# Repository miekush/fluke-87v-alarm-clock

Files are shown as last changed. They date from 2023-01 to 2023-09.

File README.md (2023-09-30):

# Fluke 87V Alarm Clock
ATMEGA328P based Alarm Clock PCB for the Fluke 87V

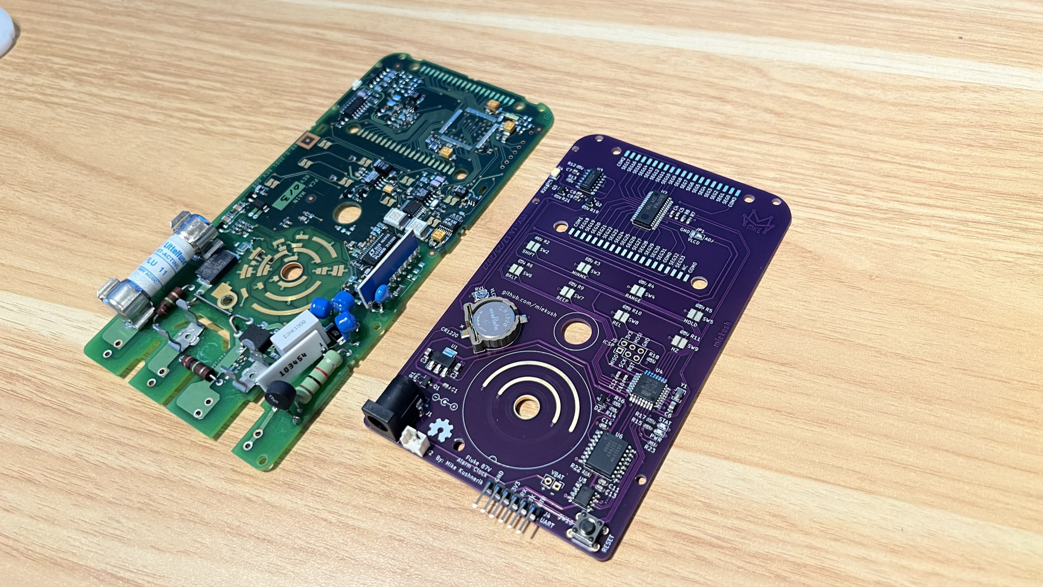
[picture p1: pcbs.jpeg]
Board Image


# Documentation

I created a full writeup for this project on Hackster.io. See the project page [HERE](https://www.hackster.io/miekush/fluke-87v-alarm-clock-af6be2)!

Update: Created another writeup for some of the recent upgrades on Hackster.io. See the project page [HERE](https://www.hackster.io/miekush/fluke-87v-alarm-clock-reloaded-a5dd7d)!

# License

MKE supports the open source hardware community by sharing hardware design files freely on GitHub!

Please support MKE by purchasing products on [Tindie](https://www.tindie.com/stores/mkengineering/)!

Designed by Mike Kushnerik (miekush)

Licensed under [Creative Commons Attribution-ShareAlike CC BY-SA 4.0](http://creativecommons.org/licenses/by-sa/4.0/)

All text above must be included in any redistribution!

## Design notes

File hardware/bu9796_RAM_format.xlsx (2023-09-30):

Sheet: Overview
 | BU9796 RAM Format
bit | 7 | 6 | 5 | 4 | 3 | 2 | 1 | 0
byte | COM0 | COM1 | COM2 | COM3 | COM0 | COM1 | COM2 | COM3
0 | SEG0 |  |  |  | SEG1
1 | SEG2 |  |  |  | SEG3
2 | SEG4 |  |  |  | SEG5
3 | SEG6 |  |  |  | SEG7
4 | SEG8 |  |  |  | SEG9
5 | SEG10 |  |  |  | SEG11
6 | SEG12 |  |  |  | SEG13
7 | SEG14 |  |  |  | SEG15
8 | SEG16 |  |  |  | SEG17
9 | SEG18 |  |  |  | SEG19

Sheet: Fluke 87V Clock Example
 | BU9796 RAM Format
bit | 7 | 6 | 5 | 4 | 3 | 2 | 1 | 0
byte | COM0 | COM1 | COM2 | COM3 | COM0 | COM1 | COM2 | COM3 | segments
0 | 5F | 5G | 5E | H4 | 5A | 5B | 5C | 5D | SEG[0:1]
1 | 4F | 4G | 4E | H3 | 4A | 4B | 4C | 4D | SEG[2:3]
2 | 3A | 3B | 3C | 3D | 3F | 3G | 3E | H2 | SEG[4:5]
3 | 2A | 2B | 2C | 2D | 2F | 2G | 2E | H1 | SEG[6:7]
4 | X2 | X36 | 1B,C | RMS | BT0 | B0 | X30 | X29 | SEG[8:9]
5 | B1 | B2 | B3 | B4 | BT1 | B7 | B6 | B5 | SEG[10:11]
6 | B8 | B9 | B10 | B11 | B15 | B14 | B13 | B12 | SEG[12:13]
7 | B24 | B25 | B26 | B27 | BT3 | B23 | B22 | B21 | SEG[14:15]
8 | B17 | B18 | B19 | B20 | BT2 | B16 | X28 | AUTO | SEG[16:17]
9 | B31 | B30 | B29 | B28 | BT4 | B32 | X26 | MAN | SEG[18:19]

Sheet: Blank Template
 | BU9796 RAM Format
bit | 7 | 6 | 5 | 4 | 3 | 2 | 1 | 0
byte | COM0 | COM1 | COM2 | COM3 | COM0 | COM1 | COM2 | COM3 | segments
0 |  |  |  |  |  |  |  |  | SEG[0:1]
1 |  |  |  |  |  |  |  |  | SEG[2:3]
2 |  |  |  |  |  |  |  |  | SEG[4:5]
3 |  |  |  |  |  |  |  |  | SEG[6:7]
4 |  |  |  |  |  |  |  |  | SEG[8:9]
5 |  |  |  |  |  |  |  |  | SEG[10:11]
6 |  |  |  |  |  |  |  |  | SEG[12:13]
7 |  |  |  |  |  |  |  |  | SEG[14:15]
8 |  |  |  |  |  |  |  |  | SEG[16:17]
9 |  |  |  |  |  |  |  |  | SEG[18:19]

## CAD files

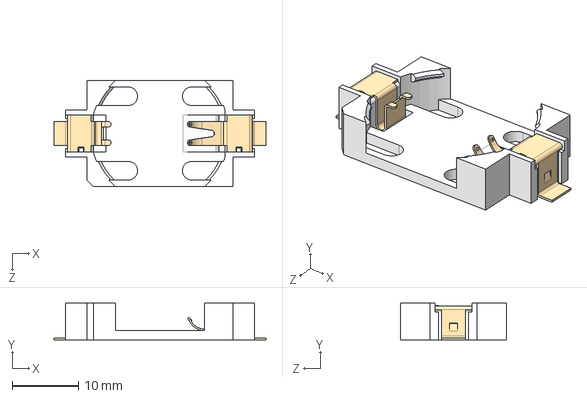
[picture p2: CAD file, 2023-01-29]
hardware/1060TR--3DModel-STEP-1.STEP
31.9 x 5.51 x 16.0 mm

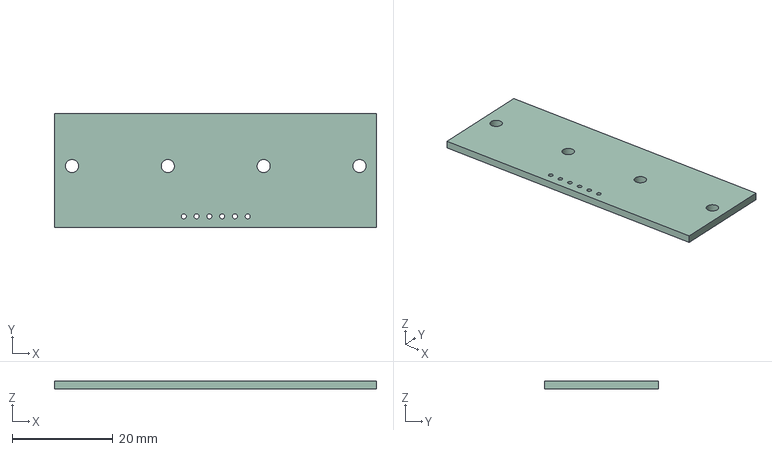
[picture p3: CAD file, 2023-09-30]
hardware/programming-adapter/fluke-87v-clock-programming-adapter.step
64.0 x 22.6 x 1.58 mm

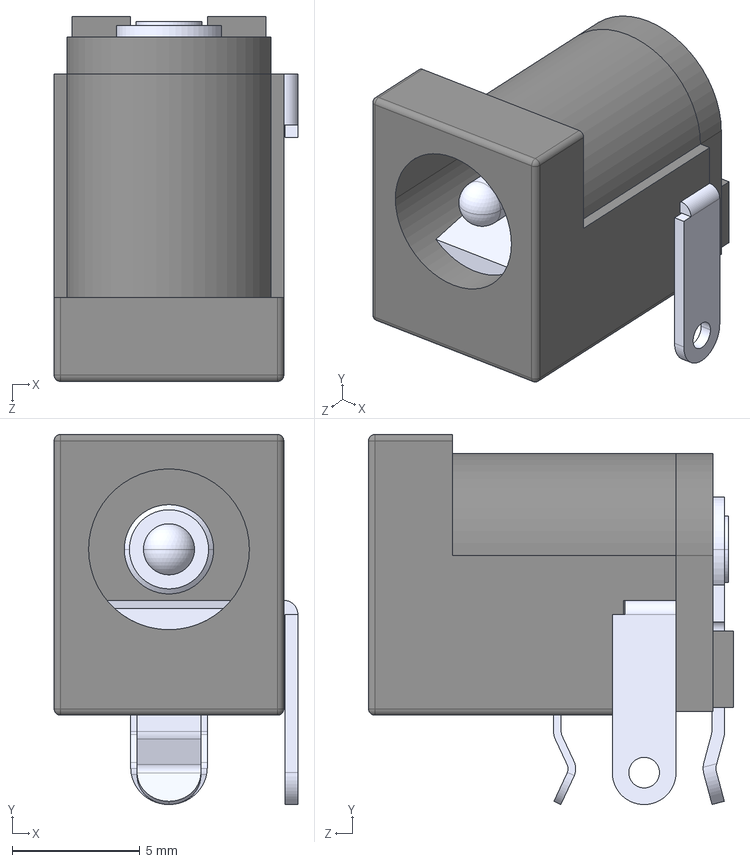
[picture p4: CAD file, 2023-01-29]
hardware/DCJ200-10-A-K1-K--3DModel-STEP-56544.STEP
9.55 x 14.5 x 14.3 mm

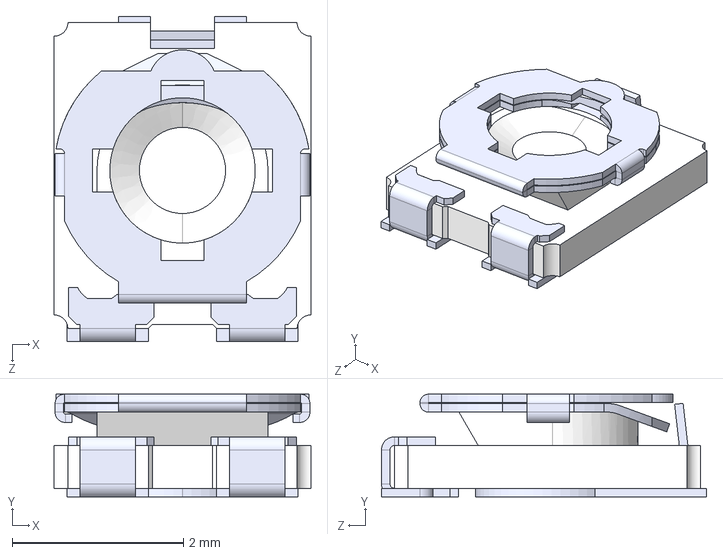
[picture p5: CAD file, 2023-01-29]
hardware/TC33X-2-104E.STEP
3.00 x 1.20 x 3.80 mm

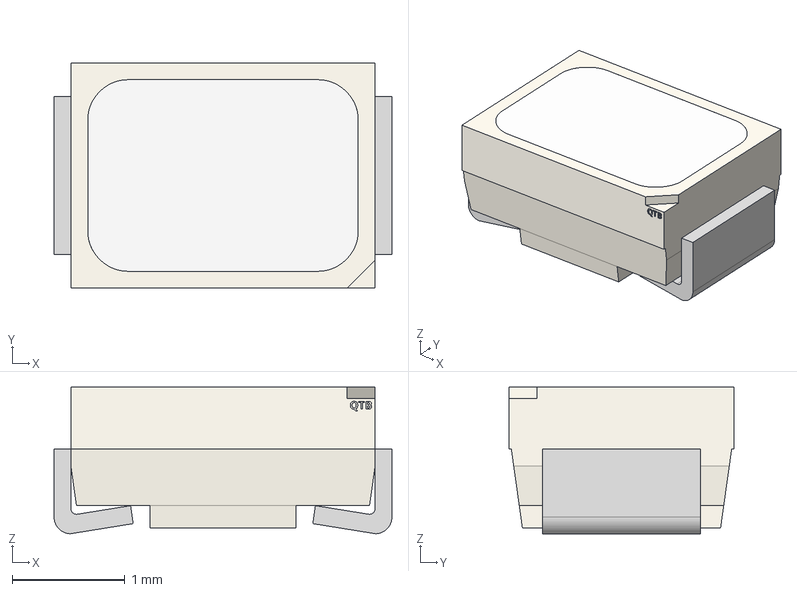
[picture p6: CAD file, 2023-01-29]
hardware/QBLP676.step
3.00 x 2.00 x 1.30 mm

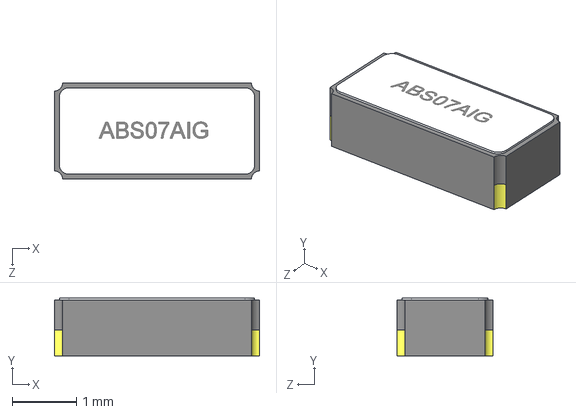
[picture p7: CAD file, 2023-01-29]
hardware/ABS07-32.768KHZ-1-T.STEP
3.20 x 0.901 x 1.50 mm

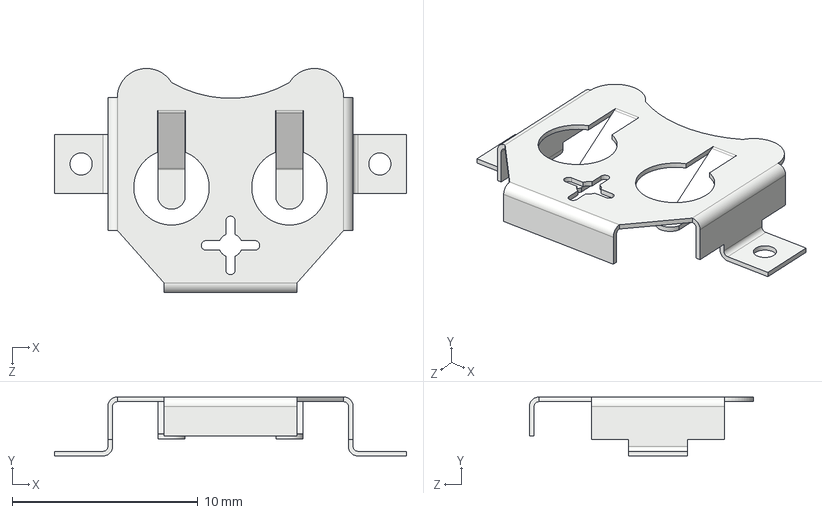
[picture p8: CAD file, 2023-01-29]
hardware/keystone-PN3000TR.STEP
18.9 x 3.17 x 12.1 mm

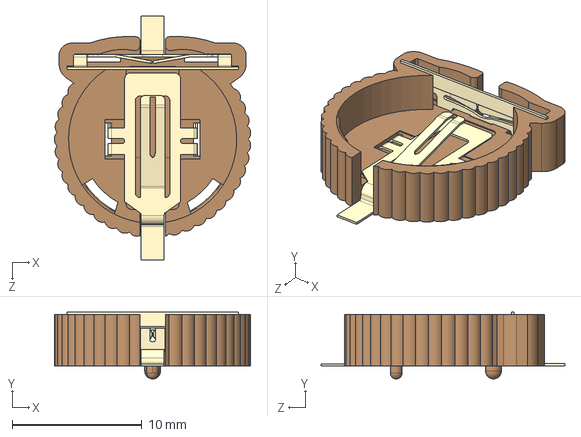
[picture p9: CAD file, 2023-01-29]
hardware/keystone-PN1056.STEP
15.1 x 5.16 x 18.8 mm

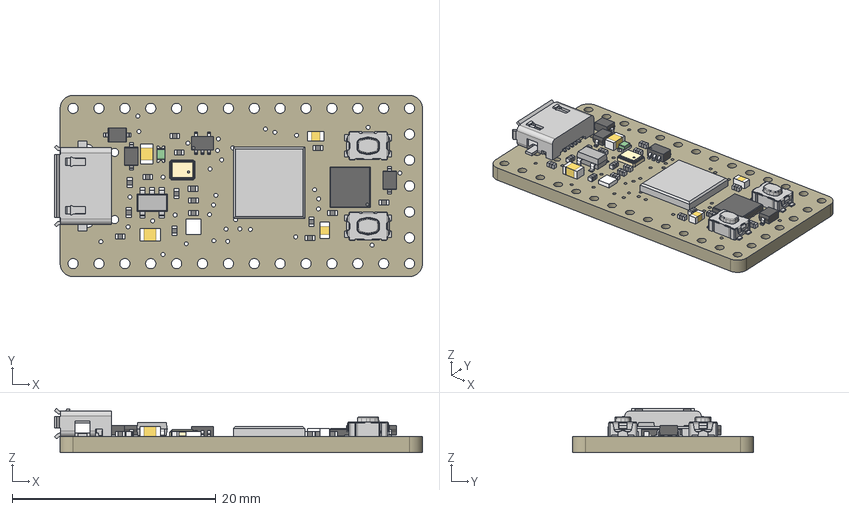
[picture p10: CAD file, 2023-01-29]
hardware/4888 ItsyBitsy RP2040.step
36.1 x 17.8 x 4.34 mm
Board
10µF x 2
RED
microUSB
AP2112K-3.3
74HCT1G125DBV
NSR0320 x 3
GD25x16
1uF x 2
RP2040_QFN56
12MHZ
KMR2 x 2
WS2812B_SK6805_1515

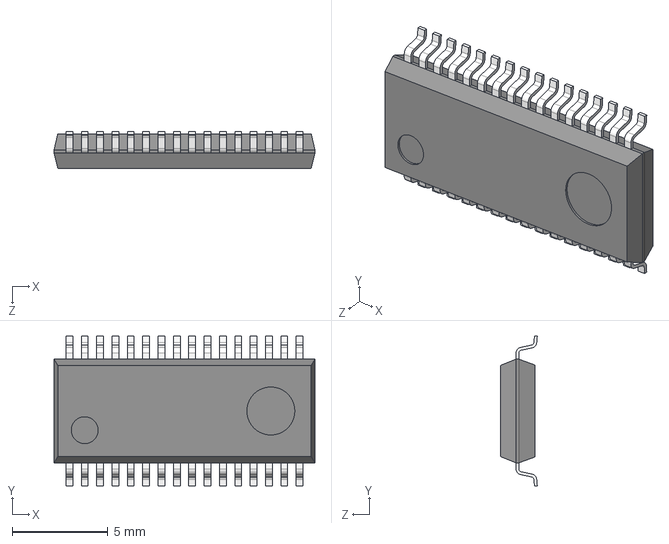
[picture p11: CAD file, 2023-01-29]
hardware/SSOP-A32_rev1.step
13.6 x 7.80 x 1.91 mm

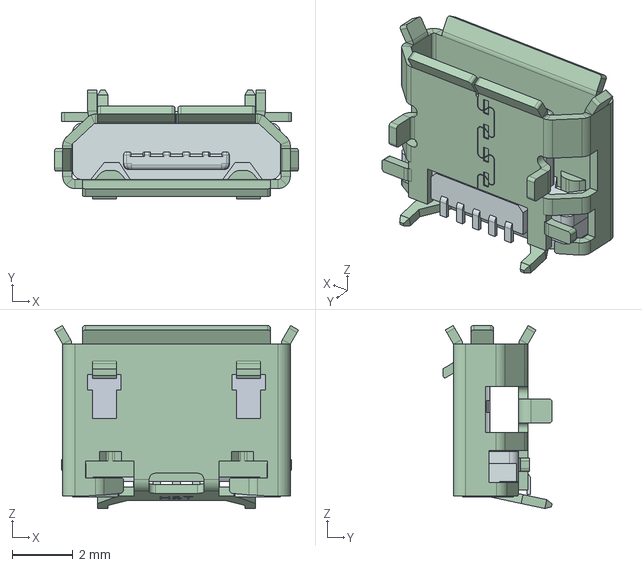
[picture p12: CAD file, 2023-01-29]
hardware/10103594.stp
8.04 x 3.60 x 6.03 mm

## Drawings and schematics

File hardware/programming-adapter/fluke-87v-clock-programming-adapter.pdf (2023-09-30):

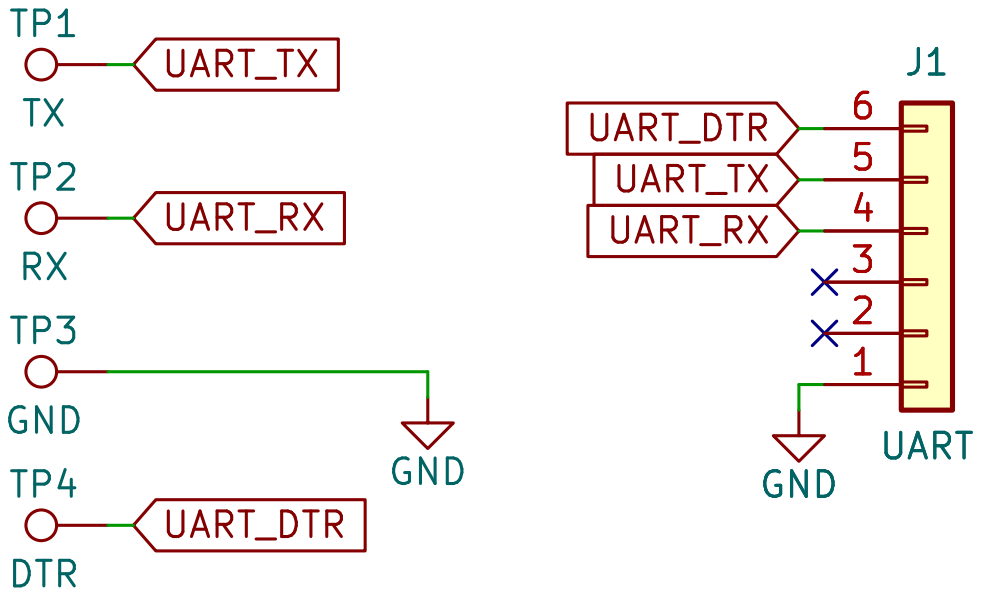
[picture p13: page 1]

Id: 1/1 Title: File: fluke-87v-clock-programming-adapter.kicad_sch Sheet: /

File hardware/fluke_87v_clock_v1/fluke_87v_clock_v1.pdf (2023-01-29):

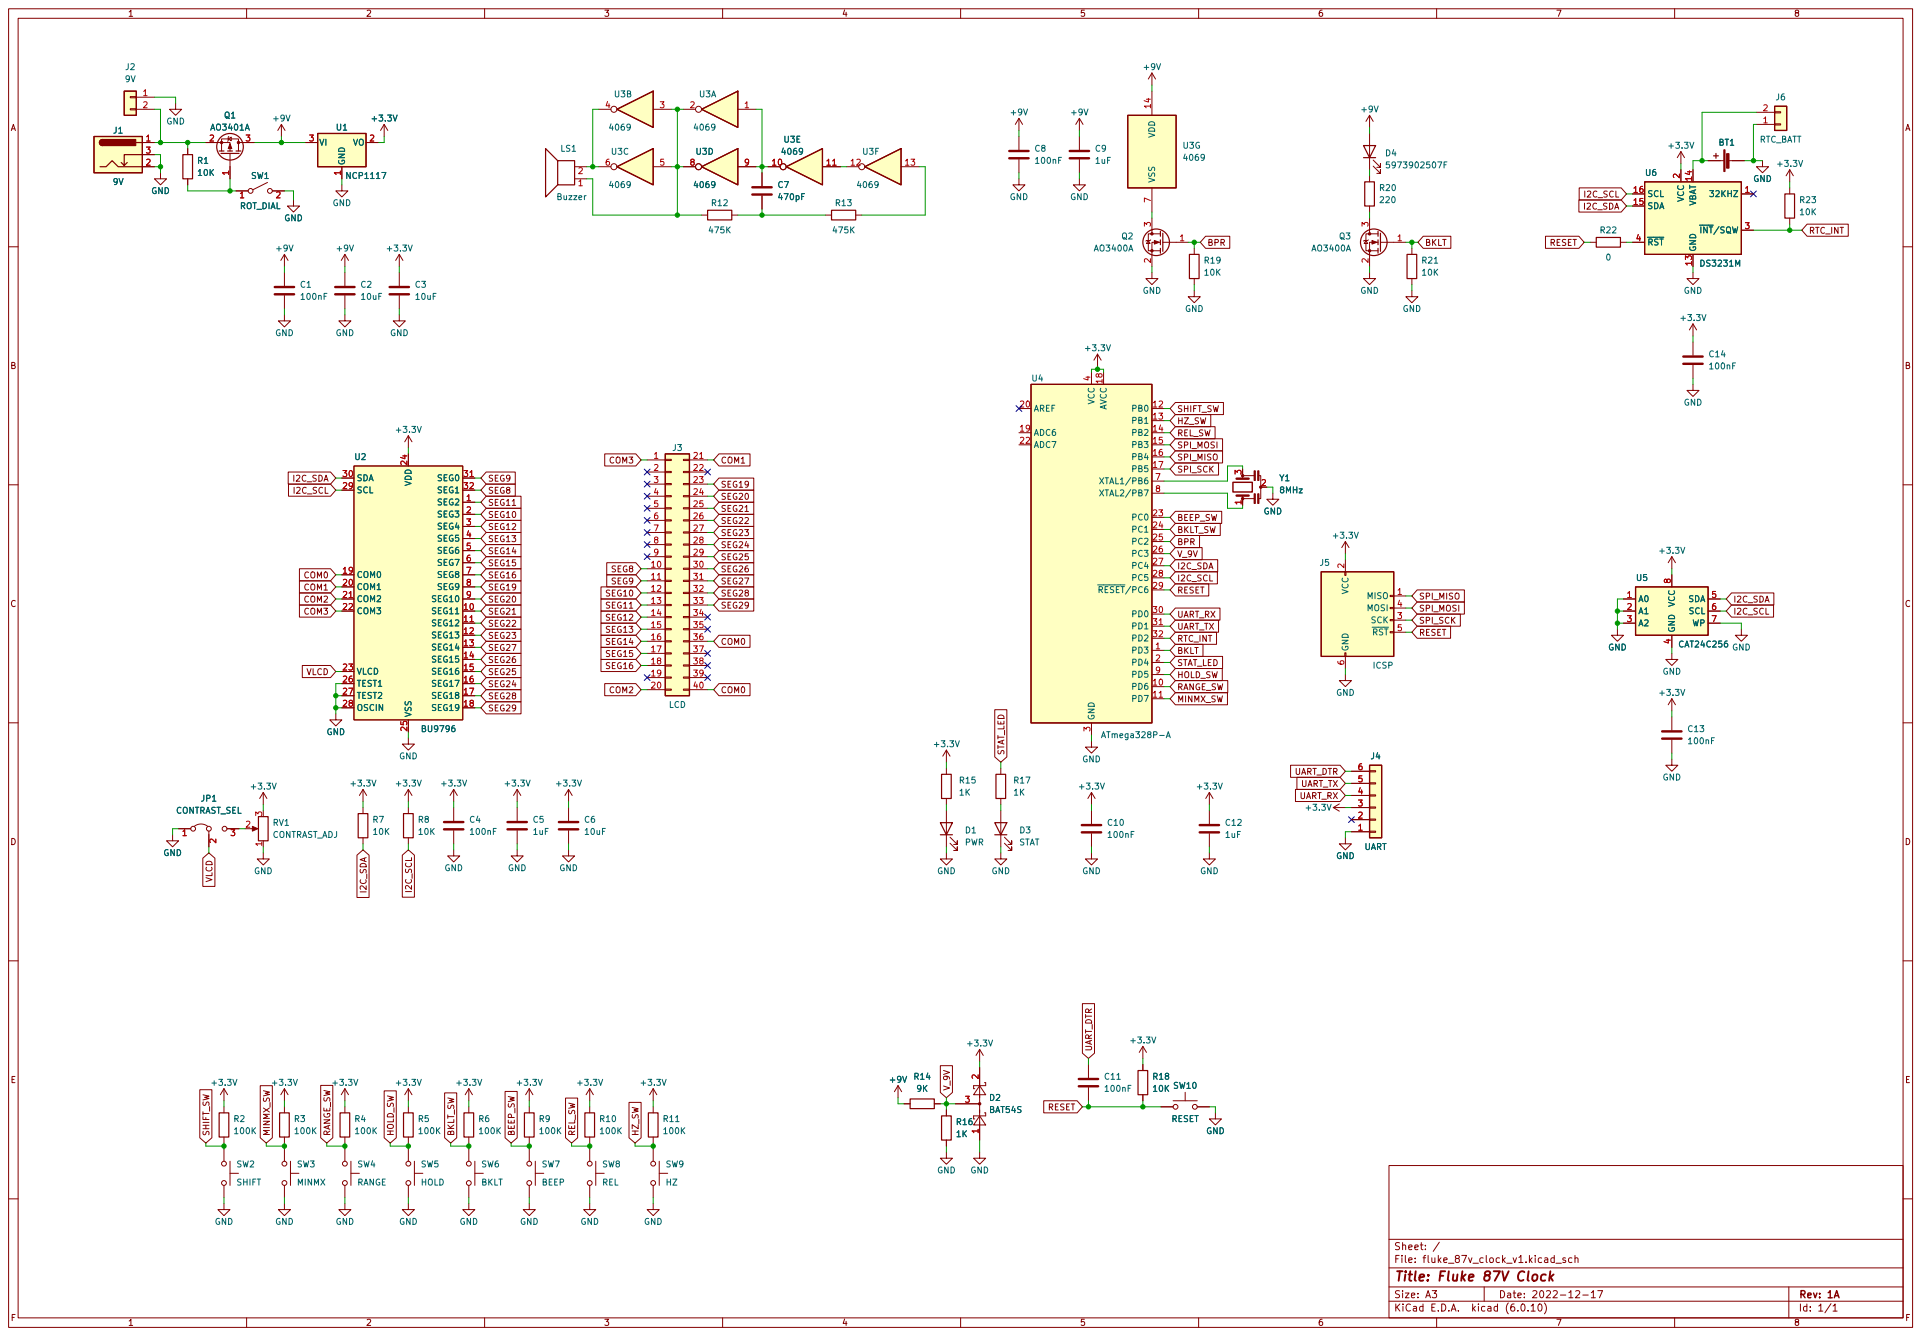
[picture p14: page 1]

2 SCK 3 MOSI 4 ~{RST} 5 GND

File: fluke_87v_clock_v1.kicad_sch Sheet: /
Id: 1/1 Title: Fluke 87V Clock

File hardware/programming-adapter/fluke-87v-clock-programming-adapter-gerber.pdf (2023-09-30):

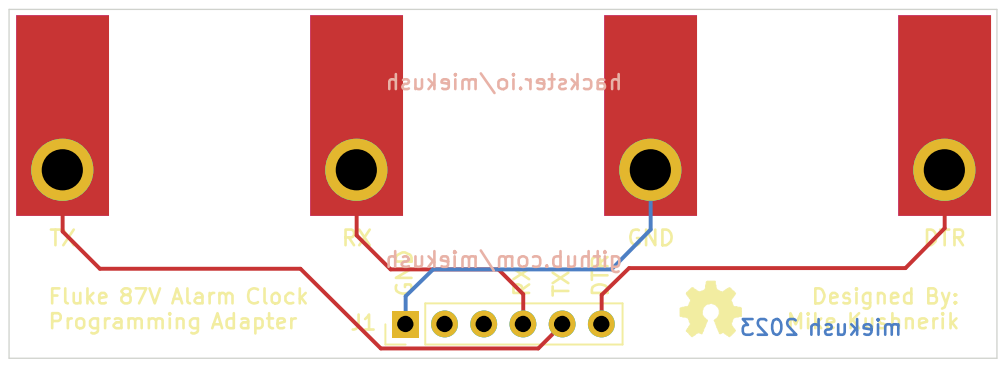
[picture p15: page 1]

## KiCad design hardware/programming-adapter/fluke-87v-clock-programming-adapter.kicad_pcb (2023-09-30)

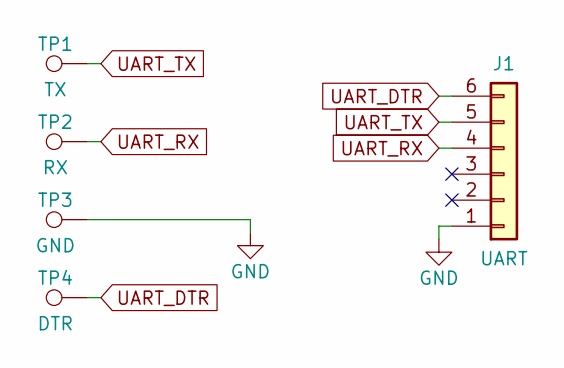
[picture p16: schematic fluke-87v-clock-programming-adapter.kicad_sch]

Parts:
J1: UART; PinHeader_1x06_P2.54mm_Vertical
TP1: TX; 4mm_banana_plug
TP2: RX; 4mm_banana_plug
TP3: GND; 4mm_banana_plug
TP4: DTR; 4mm_banana_plug

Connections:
GND: J1.1, TP3.1
UART_DTR: J1.6, TP4.1
UART_RX: J1.4, TP2.1
UART_TX: J1.5, TP1.1

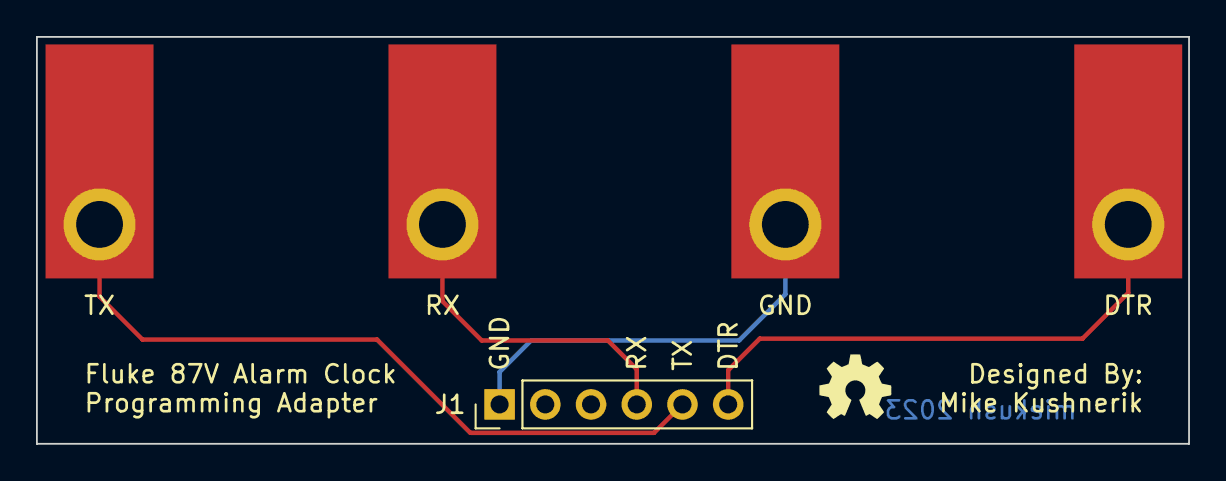
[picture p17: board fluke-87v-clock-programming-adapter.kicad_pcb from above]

Board: 2 copper layers, 64.0 x 22.6 mm, 5 parts (0 on the bottom side), 4 nets.

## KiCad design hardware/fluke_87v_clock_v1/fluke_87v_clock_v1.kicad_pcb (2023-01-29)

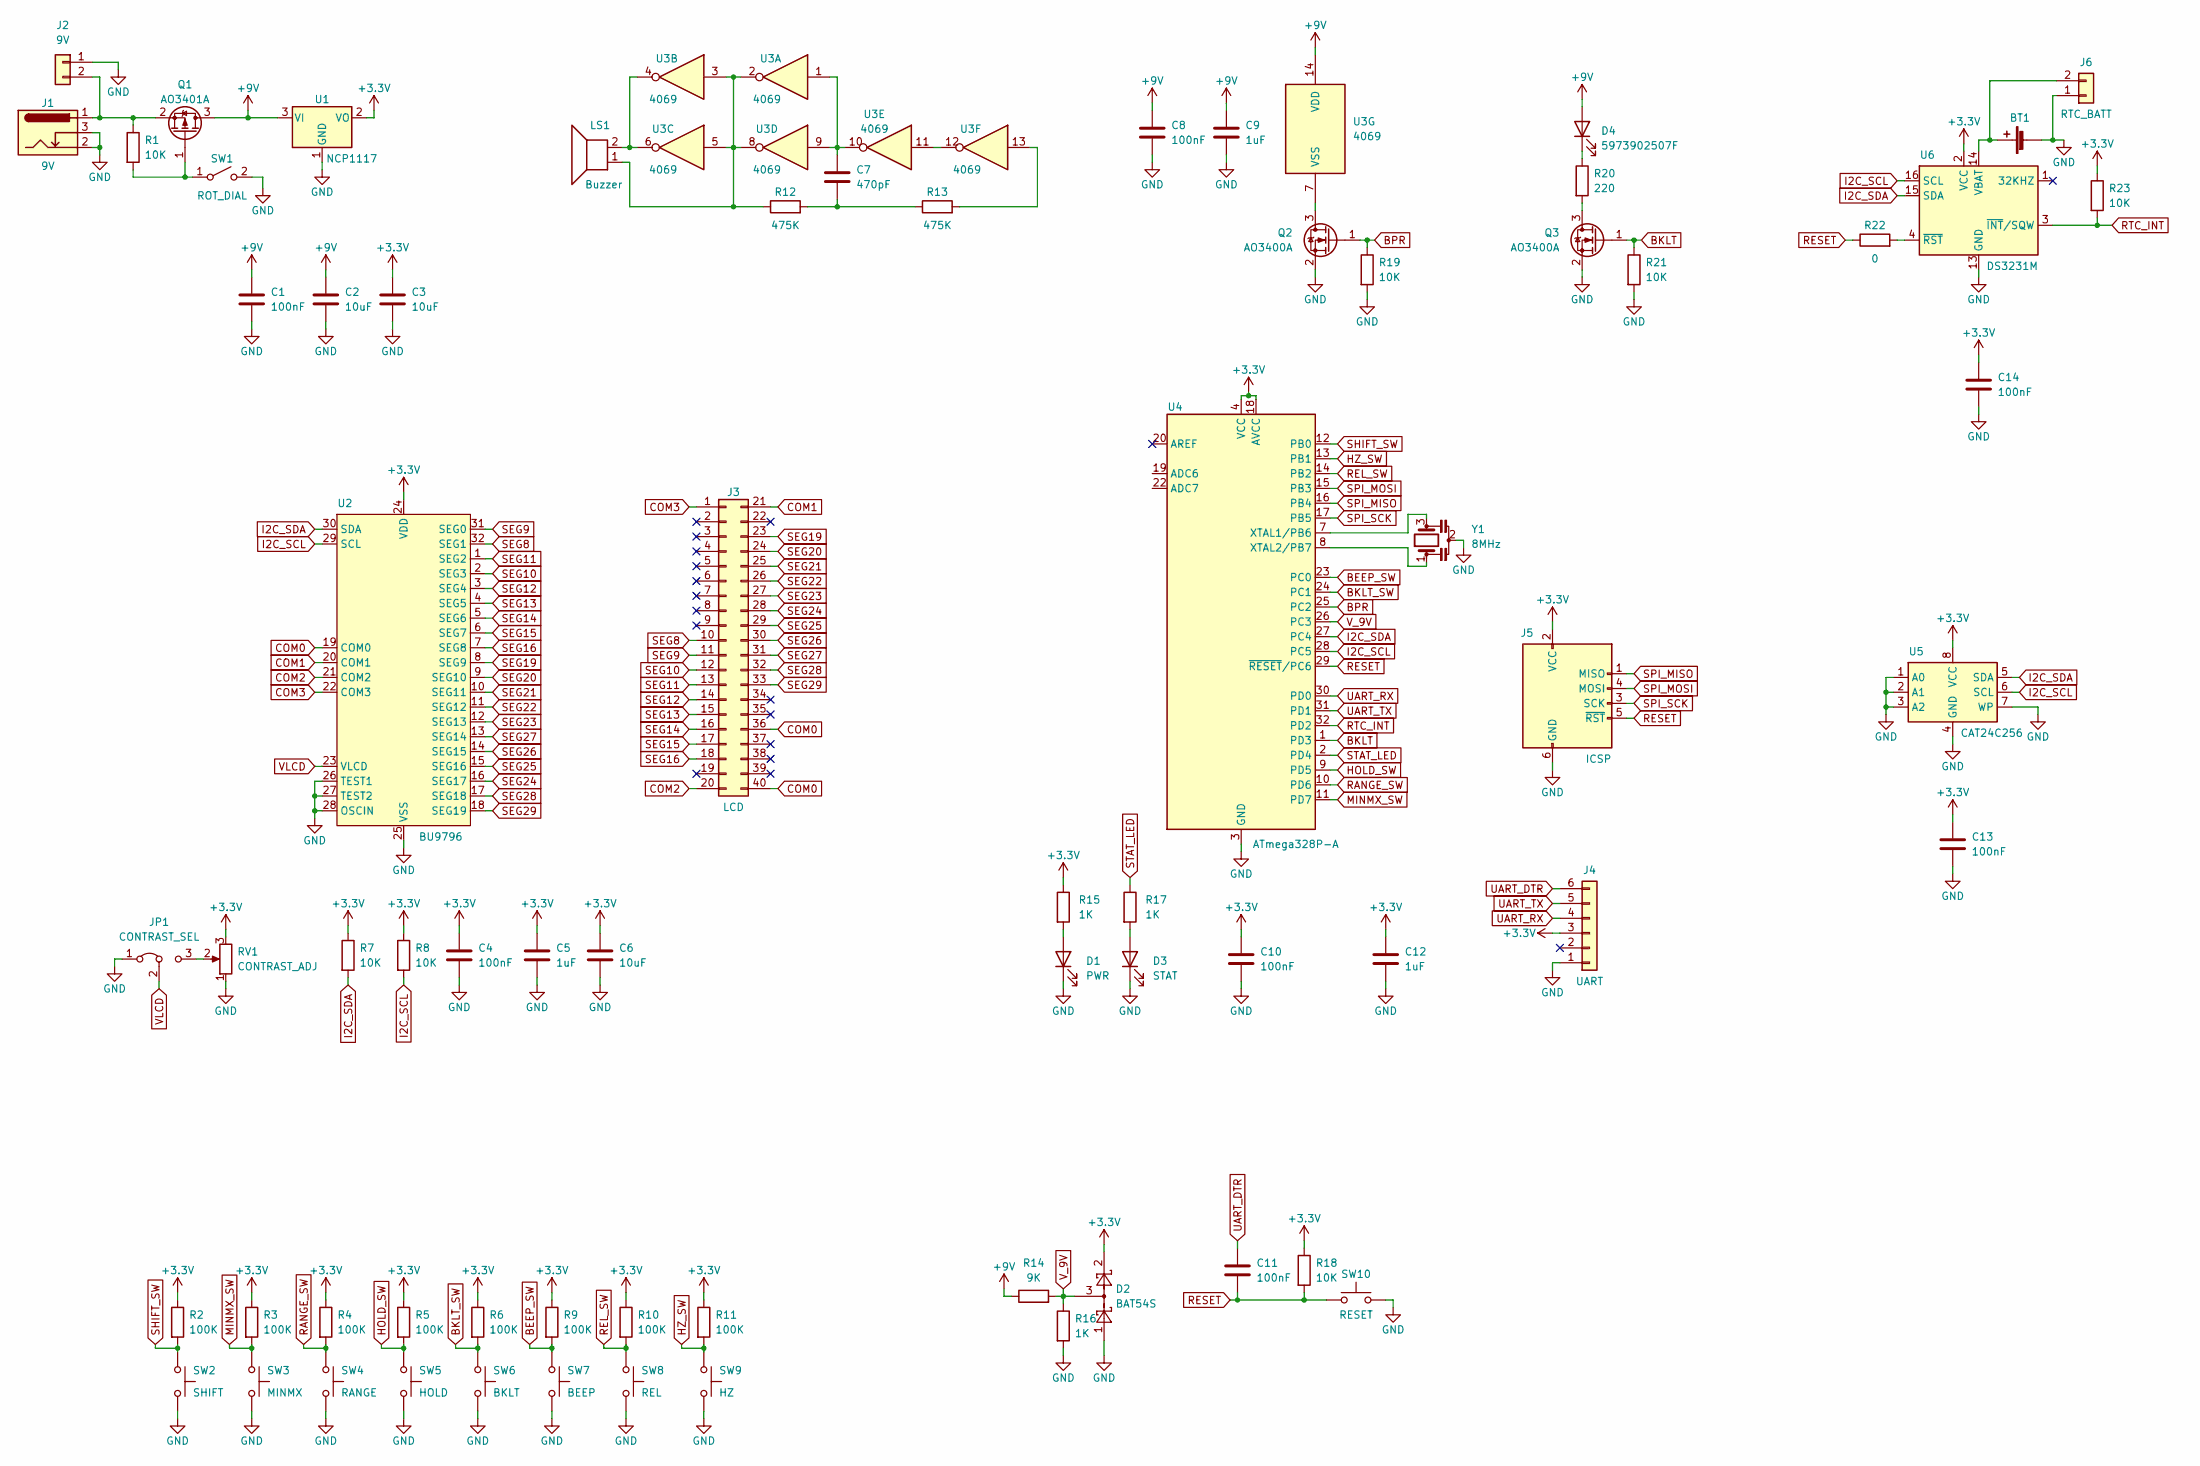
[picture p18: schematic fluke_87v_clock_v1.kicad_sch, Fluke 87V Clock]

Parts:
BT1: Battery_Cell; BAT_1056
C1, C4, C8, C10, C11, C13, C14: 100nF; C_0603_1608Metric
C2, C3, C6: 10uF; C_0805_2012Metric
C5, C9, C12: 1uF; C_0603_1608Metric
C7: 470pF; C_0603_1608Metric
D1: PWR; LED_0603_1608Metric
D2: BAT54S; SOT-23
D3: STAT; LED_0603_1608Metric
D4: 5973902507F; LED_3020
J1: 9V; BarrelJack_GCT_DCJ200-10-A_Horizontal
J2: 9V; PinHeader_1x02_P2.54mm_Vertical
J3: LCD; Fluke_87V_LCD
J4: UART; PinHeader_1x06_P2.54mm_Vertical
J5: ICSP; PinHeader_2x03_P2.54mm_Vertical
J6: RTC_BATT; PinHeader_1x02_P2.54mm_Vertical
JP1: CONTRAST_SEL; SolderJumper-3_P1.3mm_Bridged12_Pad1.0x1.5mm
LS1: Buzzer; Fluke_87V_Buzzer
Q1: AO3401A; SOT-23
Q2, Q3: AO3400A; SOT-23
R1, R7, R8, R18, R19, R21, R23: 10K; R_0603_1608Metric
R2, R3, R4, R5, R6, R9, R10, R11: 100K; R_0603_1608Metric
R12, R13: 475K; R_0603_1608Metric
R14: 9K; R_0603_1608Metric
R15, R16, R17: 1K; R_0603_1608Metric
R20: 220; R_0805_2012Metric
R22: 0; R_0603_1608Metric
RV1: CONTRAST_ADJ; Potentiometer_Bourns_TC33X_Vertical
SW1: ROT_DIAL; Fluke_87V_Rotary_Dial
SW2: SHIFT; Fluke_87V_Membrane_SW
SW3: MINMX; Fluke_87V_Membrane_SW
SW4: RANGE; Fluke_87V_Membrane_SW
SW5: HOLD; Fluke_87V_Membrane_SW
SW6: BKLT; Fluke_87V_Membrane_SW
SW7: BEEP; Fluke_87V_Membrane_SW
SW8: REL; Fluke_87V_Membrane_SW
SW9: HZ; Fluke_87V_Membrane_SW
SW10: RESET; SW_PUSH_6mm
U1: NCP1117; SOT-223-3_TabPin2
U2: BU9796; SSOP-A32
U3: 4069; SOIC-14_3.9x8.7mm_P1.27mm
U4: ATmega328P-A; TQFP-32_7x7mm_P0.8mm
U5: CAT24C256; SOIC-8_3.9x4.9mm_P1.27mm
U6: DS3231M; SOIC-16W_7.5x10.3mm_P1.27mm
Y1: 8MHz; Resonator_SMD_Murata_CSTxExxV-3Pin_3.0x1.1mm

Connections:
+3V3: C3.1, C4.1, C5.1, C6.1, C10.1, C12.1, C13.1, C14.1, D2.2, J4.3, J5.2 (VCC), R2.1, R3.1, R4.1, R5.1, R6.1, R7.1, R8.1, R9.1, R10.1, R11.1, R15.1, R18.1, R23.1, RV1.3, U1.2 (VO), U2.24 (VDD), U4.4 (VCC), U4.6 (VCC), U4.18 (AVCC), U5.8 (VCC), U6.2 (VCC)
+9V: C1.1, C2.1, C8.1, C9.1, D4.2 (A), Q1.3 (D), R14.1, U1.3 (VI), U3.14 (VDD)
BEEP_SW: R9.2, SW7.1, U4.23 (PC0)
BKLT: Q3.1 (G), R21.1, U4.1 (PD3)
BKLT_SW: R6.2, SW6.1, U4.24 (PC1)
BPR: Q2.1 (G), R19.1, U4.25 (PC2)
COM0: J3.36, J3.40, U2.19 (COM0)
COM1: J3.21, U2.20 (COM1)
COM2: J3.20, U2.21 (COM2)
COM3: J3.1, U2.22 (COM3)
GND: BT1.2 (-), C1.2, C2.2, C3.2, C4.2, C5.2, C6.2, C8.2, C9.2, C10.2, C12.2, C13.2, C14.2, D1.1 (K), D2.1, D3.1 (K), J1.2, J1.3, J2.1, J4.1, J5.6 (GND), J6.1, JP1.1 (A), Q2.2 (S), Q3.2 (S), R16.2, R19.2, R21.2, RV1.1, SW1.2 (B), SW2.2, SW3.2, SW4.2, SW5.2, SW6.2, SW7.2, SW8.2, SW9.2, SW10.2, U1.1 (GND), U2.25 (VSS), U2.26 (TEST1), U2.27 (TEST2), U2.28 (OSCIN), U4.3 (GND), U4.5 (GND), U4.21 (GND), U5.1 (A0), U5.2 (A1), U5.3 (A2), U5.4 (GND), U5.7 (WP), U6.5 (GND), U6.6 (GND), U6.7 (GND), U6.8 (GND), U6.9 (GND), U6.10 (GND), U6.11 (GND), U6.12 (GND), U6.13 (GND), Y1.2
HOLD_SW: R5.2, SW5.1, U4.9 (PD5)
HZ_SW: R11.2, SW9.1, U4.13 (PB1)
I2C_SCL: R8.2, U2.29 (SCL), U4.28 (PC5), U5.6 (SCL), U6.16 (SCL)
I2C_SDA: R7.2, U2.30 (SDA), U4.27 (PC4), U5.5 (SDA), U6.15 (SDA)
MINMX_SW: R3.2, SW3.1, U4.11 (PD7)
unnamed: BT1.1 (+), J6.2, U6.14 (VBAT)
unnamed: C7.1, U3.1, U3.9, U3.10
unnamed: C7.2, R12.2, R13.1
unnamed: D1.2 (A), R15.2
unnamed: D3.2 (A), R17.2
unnamed: D4.1 (K), R20.1
unnamed: J1.1, J2.2, Q1.2 (S), R1.1
unnamed: JP1.3 (B), RV1.2
unnamed: LS1.1, R12.1, U3.2, U3.3, U3.5, U3.8
unnamed: LS1.2, U3.4, U3.6
unnamed: Q1.1 (G), R1.2, SW1.1 (A)
unnamed: Q2.3 (D), U3.7 (VSS)
unnamed: Q3.3 (D), R20.2
unnamed: R13.2, U3.13
unnamed: R22.2, U6.4 (~RST)
unnamed: U3.11, U3.12
unnamed: U4.7 (XTAL1/PB6), Y1.3
unnamed: U4.8 (XTAL2/PB7), Y1.1
RANGE_SW: R4.2, SW4.1, U4.10 (PD6)
REL_SW: R10.2, SW8.1, U4.14 (PB2)
RESET: C11.2, J5.5 (~RST), R18.2, R22.1, SW10.1, U4.29 (~RESET/PC6)
RTC_INT: R23.2, U4.32 (PD2), U6.3 (~INT/SQW)
SEG8: J3.10, U2.32 (SEG1)
SEG9: J3.11, U2.31 (SEG0)
SEG10: J3.12, U2.2 (SEG3)
SEG11: J3.13, U2.1 (SEG2)
SEG12: J3.14, U2.3 (SEG4)
SEG13: J3.15, U2.4 (SEG5)
SEG14: J3.16, U2.5 (SEG6)
SEG15: J3.17, U2.6 (SEG7)
SEG16: J3.18, U2.7 (SEG8)
SEG19: J3.23, U2.8 (SEG9)
SEG20: J3.24, U2.9 (SEG10)
SEG21: J3.25, U2.10 (SEG11)
SEG22: J3.26, U2.11 (SEG12)
SEG23: J3.27, U2.12 (SEG13)
SEG24: J3.28, U2.16 (SEG17)
SEG25: J3.29, U2.15 (SEG16)
SEG26: J3.30, U2.14 (SEG15)
SEG27: J3.31, U2.13 (SEG14)
SEG28: J3.32, U2.17 (SEG18)
SEG29: J3.33, U2.18 (SEG19)
SHIFT_SW: R2.2, SW2.1, U4.12 (PB0)
SPI_MISO: J5.1 (MISO), U4.16 (PB4)
SPI_MOSI: J5.4 (MOSI), U4.15 (PB3)
SPI_SCK: J5.3 (SCK), U4.17 (PB5)
STAT_LED: R17.1, U4.2 (PD4)
UART_DTR: C11.1, J4.6
UART_RX: J4.4, U4.30 (PD0)
UART_TX: J4.5, U4.31 (PD1)
VLCD: JP1.2 (C), U2.23 (VLCD)
V_9V: D2.3, R14.2, R16.1, U4.26 (PC3)

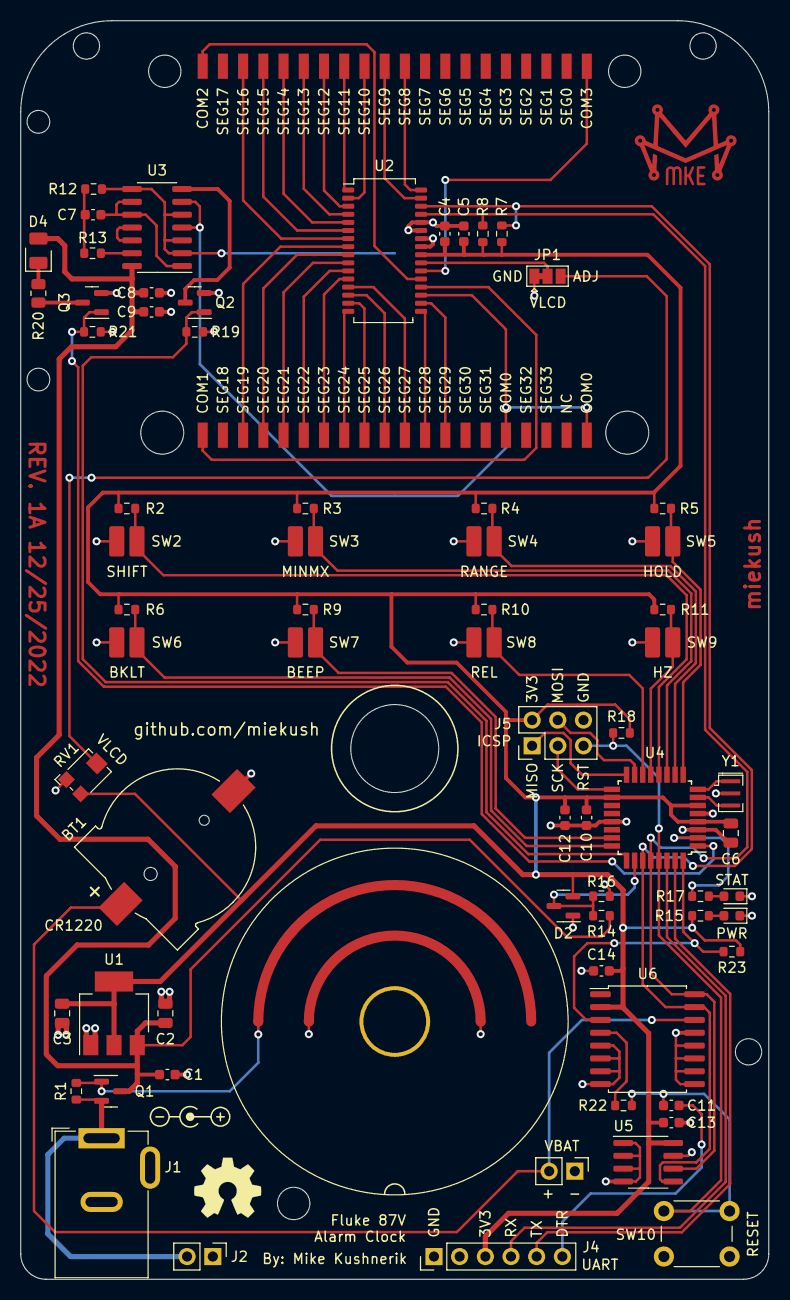
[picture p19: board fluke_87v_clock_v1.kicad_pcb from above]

Board: 2 copper layers, 74.0 x 124.5 mm, 71 parts (1 on the bottom side), 68 nets.

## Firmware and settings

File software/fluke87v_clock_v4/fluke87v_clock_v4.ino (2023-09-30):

#include "bu9796.h"
#include "RTClib.h"
#include "TimerOne.h"
#include "EEPROM.h"

//output pins
#define STAT_LED_PIN    4
#define BKLT_PIN        3
#define BZR_PIN         16

//digital input pins 
#define SHIFT_SW_PIN    8
#define MINMX_SW_PIN    7
#define RANGE_SW_PIN    6
#define HOLD_SW_PIN     5
#define BKLT_SW_PIN     15
#define BEEP_SW_PIN     14
#define REL_SW_PIN      10
#define HZ_SW_PIN       9
#define RTC_INT_PIN     2

//analog input pins
#define BAT_V_PIN       A3

//button switch pins
#define SHIFT_SW        0
#define MINMX_SW        1
#define RANGE_SW        2
#define HOLD_SW         3
#define BKLT_SW         4
#define BEEP_SW         5
#define REL_SW          6
#define HZ_SW           7

//format:
//{pin number, current state, previous state, press time}
uint8_t switch_pins[8][4] =
{
  {SHIFT_SW_PIN,1,1,0},
  {MINMX_SW_PIN,1,1,0},
  {RANGE_SW_PIN,1,1,0},
  {HOLD_SW_PIN,1,1,0},
  {BKLT_SW_PIN,1,1,0},
  {BEEP_SW_PIN,1,1,0},
  {REL_SW_PIN,1,1,0},
  {HZ_SW_PIN,1,1,0}
};

BU9796 display;
RTC_DS3231 rtc;

bool rtc_interruptFlag = false;
bool alarmFlag = false;

bool beepFlag = false;
bool doubleBeepFlag = false;

bool holdFlag = false;

bool alarmSettingsMode = false;
bool setAlarmFlag = false;
bool updateAlarmDisplay = false;
uint8_t alarmTimeInterval = 30;

bool barGraphFlag = true;

//wakeup alarm
DateTime alarm = DateTime(2022, 1, 23, 6, 30, 0);

void buzzerBeep(int ms, int count = 1);

void setup()
{
  //init uart
  Serial.begin(9600);

  //init peripheral devices
  display.begin();
  rtc.begin();

  //disable 32 kHz output
  rtc.disable32K();

  //init output pins
  pinMode(STAT_LED_PIN, OUTPUT);
  pinMode(BKLT_PIN, OUTPUT);
  pinMode(BZR_PIN, OUTPUT);

  //init input pins
  pinMode(SHIFT_SW_PIN, INPUT);
  pinMode(MINMX_SW_PIN, INPUT);
  pinMode(RANGE_SW_PIN, INPUT);
  pinMode(HOLD_SW_PIN, INPUT);
  pinMode(BKLT_SW_PIN, INPUT);
  pinMode(BEEP_SW_PIN, INPUT);
  pinMode(REL_SW_PIN, INPUT);
  pinMode(HZ_SW_PIN, INPUT);
  pinMode(RTC_INT_PIN, INPUT);

  //turn backlight off by default
  digitalWrite(BKLT_PIN, LOW);

  //turn buzzer off
  digitalWrite(BZR_PIN, LOW);

  //attach interrupt to RTC INT pin
  attachInterrupt(digitalPinToInterrupt(RTC_INT_PIN), rtcISR, FALLING);

  //clear alarms
  rtc.clearAlarm(1);
  rtc.clearAlarm(2);

  //turn off squarewave output
  rtc.writeSqwPinMode(DS3231_OFF);

  //rtc calibration mode
  if(!digitalRead(MINMX_SW_PIN))
  {
    //write CAL to display
    display.writeChar(31,12,10,19);
    display.update();

    while(1)
    {
      if(Serial.available())
      {
        String datetime = Serial.readStringUntil('\n');
        char datetime_array[datetime.length()+1];
        datetime.toCharArray(datetime_array, datetime.length());

        //Serial datetime format:
        //YYYYMMDDHHMMSSWWyyy\n
        //YYYY -> year
        //MM   -> month
        //DD   -> day
        //HH   -> hour
        //MM   -> minute
        //SS   -> second
        //WW   -> weekday
        //yy   -> yearday (1-365)

        int year = ((datetime_array[0] - '0') * 1000) + ((datetime_array[1] - '0') * 100) + ((datetime_array[2] - '0') * 10) + (datetime_array[3] - '0');
        int month = ((datetime_array[4] - '0') * 10) + (datetime_array[5] - '0');
        int day = ((datetime_array[6] - '0') * 10) + (datetime_array[7] - '0');
        int hour = ((datetime_array[8] - '0') * 10) + (datetime_array[9] - '0');
        int min = ((datetime_array[10] - '0') * 10) + (datetime_array[11] - '0');
        int second = ((datetime_array[12] - '0') * 10) + (datetime_array[13] - '0');
        //int weekday = ((datetime_array[14] - '0') * 10) + (datetime_array[15] - '0');
        //int yearday = ((datetime_array[16] - '0') * 100) + ((datetime_array[17] - '0') * 10) + (datetime_array[18] - '0');

        rtc.adjust(DateTime(year, month, day, hour, min, second));

        flashBacklight(100);
      }
    }
  }  

  //create timer for polling switches
  Timer1.initialize(100000); //100ms
  Timer1.attachInterrupt(pollSwitches);

  //read alarm time from EEPROM
  uint8_t hours = EEPROM.read(0);
  uint8_t minutes = EEPROM.read(1);

  uint8_t remainder = minutes % alarmTimeInterval;

  if(remainder != 0)
  {
    //round up
    if(remainder >= (alarmTimeInterval/2))
    {
      minutes = (minutes-remainder) + alarmTimeInterval;
    }
    //round down
    else
    {
      minutes = minutes-remainder;
    }
  }

  if(hours != 255 && minutes != 255)
  {
    alarm = DateTime(2022, 1, 23, hours, minutes, 0);
  }

  //disable alarm on startup
  rtc.disableAlarm(2);

  //configure RTC alarm every minute
  rtc.setAlarm1(rtc.now(), DS3231_A1_PerSecond);

  //write latest rtc time to display
  updateDisplayTime(rtc.now());
}

void loop()
{
  if(alarmSettingsMode && updateAlarmDisplay)
  {
    updateDisplayTime(alarm);
    display.blink(2000);
    updateAlarmDisplay = false;
  }
  else if(rtc_interruptFlag && !alarmSettingsMode)
  {
    //get latest time from RTC and write to display
    updateDisplayTime(rtc.now());

    //reset flag
    rtc_interruptFlag = false;

    //alarm 2 caused interrupt
    if(rtc.alarmFired(2))
    {
      //clear alarm
      rtc.clearAlarm(1);
      rtc.clearAlarm(2);

      if(alarmFlag)
      {
        //blink display segments (1 Hz)
        display.blink(1000);

        //alarm loop until reset
        while(1)
        {
          toggleBacklight();
          buzzerBeep(1000);
          toggleBacklight();
          delay(1000);
        }
      }
    }
    //alarm 1 caused interrupt
    else
    {
      //clear alarm
      rtc.clearAlarm(1);
    }
  }

  //single beep request (i.e. button press)
  if(beepFlag)
  {
    buzzerBeep(100);
    beepFlag = false;
  }

  if(doubleBeepFlag)
  {
    buzzerBeep(100, 2);
    doubleBeepFlag = false;
  }

  if(holdFlag)
  {
    displayBatteryVoltage();
    delay(500);
  }
  
  if(setAlarmFlag)
  {
    if(alarmFlag)
    {
      //write new alarm time to RTC
      rtc.setAlarm2(alarm, DS3231_A2_Hour);
      //write new alarm time to EEPROM
      EEPROM.update(0, alarm.hour());
      EEPROM.update(1, alarm.minute());
      //turn off blink
      display.blink(0);
    }
    else
    {
      rtc.disableAlarm(2);
    }
    setAlarmFlag = false;
  }
}

void rtcISR()
{
  rtc_interruptFlag = true;
}

void updateDisplayTime(DateTime time)
{
  //write time to display
  display.writeValue((time.twelveHour() * 100) + time.minute());
  display.setDecimalPoint(3);

  //check for if time is PM
  if(time.isPM())
  {
    //indicate PM time
    display.setMinusSign();
  }

  //check if alarm is set
  if(alarmFlag)
  {
    //indicate HOLD symbol
    display.setHoldSymbol();
  }

  //check if bargraph is enabled
  if(barGraphFlag && !alarmSettingsMode && time.second() != 0)
  {
    display.setBarGraph(time.second()/2);
  }

  //display.setSegment(7, 7);

  display.update();
}

void displayBatteryVoltage(void)
{
  //read battery voltage
  int battV = 10.1 * (3300.0 * (analogRead(BAT_V_PIN) / 1023.0));
  display.writeValue(battV);
  display.update();
}

void pollSwitches(void)
{
  for(int i=0; i<8; i++)
  {
    //read current values of all switches
    switch_pins[i][1] = digitalRead(switch_pins[i][0]);

    switch(i)
    {
      case SHIFT_SW:
        //falling edge
        if(switch_pins[i][1] == LOW && switch_pins[i][2] == HIGH)
        {
          holdFlag = true;
          
          if(alarmSettingsMode)
          {
            setAlarmFlag = true;
            alarmSettingsMode = false;
            doubleBeepFlag = true;
          }
        }
        //rising edge
        else if(switch_pins[i][1] == HIGH && switch_pins[i][2] == LOW)
        {
          holdFlag = false;
          rtc_interruptFlag = true;
          //reset counter
          switch_pins[i][3] = 0;
        }
        break;
      case MINMX_SW:
        break;
      case RANGE_SW:
        //falling edge
        if(switch_pins[i][1] == LOW && switch_pins[i][2] == HIGH && alarmSettingsMode)
        {
          alarm = alarm + TimeSpan(0,0,alarmTimeInterval,0);
          updateAlarmDisplay = true;
          beepFlag = true;
        }
        break;
      case HOLD_SW:
        break;
      case BKLT_SW:
        //falling edge
        if(switch_pins[i][1] == LOW && switch_pins[i][2] == HIGH)
        {
          toggleBacklight();
          beepFlag = true;
        }
        break;
      case BEEP_SW:
        //falling edge
        if(switch_pins[i][1] == LOW && switch_pins[i][2] == HIGH)
        {
        }
        //still pressed
        else if(switch_pins[i][1] == LOW && switch_pins[i][2] == LOW)
        {
          //increment counter
          switch_pins[i][3]++;

          if(switch_pins[i][3] > 15 && alarmSettingsMode == false && alarmFlag == true)
          {
            doubleBeepFlag = true;
            alarmSettingsMode = true;
            updateAlarmDisplay = true;
          }
        }
        //rising edge
        else if(switch_pins[i][1] == HIGH && switch_pins[i][2] == LOW)
        {
          if(switch_pins[i][3] <= 15)
          {
            if(alarmSettingsMode)
            {
              setAlarmFlag = true;
              alarmSettingsMode = false;
              doubleBeepFlag = true;
            }
            else
            {
              alarmFlag = !alarmFlag;
              setAlarmFlag = true;
              beepFlag = true;
            }
            rtc_interruptFlag = true;
          }
          //reset counter
          switch_pins[i][3] = 0;
        }
        break;
      case REL_SW:
        //falling edge
        if(switch_pins[i][1] == LOW && switch_pins[i][2] == HIGH && alarmSettingsMode)
        {
          alarm = alarm - TimeSpan(0,0,alarmTimeInterval,0);
          updateAlarmDisplay = true;
          beepFlag = true;
        }
        break;
      case HZ_SW:
        break;
      default:
        break;
    }
  }

  for(int j=0; j<8; j++)
  {
    //copy value of current to previous
    switch_pins[j][2] = switch_pins[j][1];
  }
}

void toggleBacklight(void)
{
  //toggle bklt pin
  digitalWrite(BKLT_PIN, !digitalRead(BKLT_PIN));
}

void flashBacklight(int ms)
{
  digitalWrite(BKLT_PIN, HIGH);
  delay(ms);
  digitalWrite(BKLT_PIN, LOW);
}

void buzzerBeep(int ms, int count)
{
  for(int i=0; i<count; i++)
  {
    digitalWrite(BZR_PIN, HIGH);
    delay(ms);
    digitalWrite(BZR_PIN, LOW);
    delay(ms);
  }
}

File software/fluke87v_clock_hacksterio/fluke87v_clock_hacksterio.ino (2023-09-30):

#include "bu9796.h"

//output pins
#define BKLT_PIN        3

BU9796 display;

void setup()
{
  //init peripheral devices
  display.begin();

  //init output pins
  pinMode(BKLT_PIN, OUTPUT);

  //turn backlight off by default
  digitalWrite(BKLT_PIN, HIGH);
}

void loop()
{
  //hACK
  display.clearBuffer();
  display.writeChar(16, 10, 12, 20);
  display.update();
  delay(1000);
  //STER
  display.clearBuffer();
  display.writeChar(27, 28, 14, 26);
  display.update();
  delay(1000);
  //.io
  display.clearBuffer();
  display.setDecimalPoint(1);
  display.writeChar(18, 23, 33, 33);
  display.update();
  delay(2500);
}

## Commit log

2023-01-29 Initial upload
    [10103594.stp, 1060TR--3DModel-STEP-1.STEP, 4888 ItsyBitsy RP2040.step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]
2023-09-30 Update files
    [bu9796_RAM_format.xlsx, fluke-87v-clock-programming-adapter.kicad_pcb, fluke-87v-clock-programming-adapter.kicad_sch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]
